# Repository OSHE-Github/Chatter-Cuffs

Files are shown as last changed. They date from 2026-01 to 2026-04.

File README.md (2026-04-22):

# Chatter Cuff
Chatter Cuff is a wrist mounted walkie talkie intended for outdoor sporting enthusiasts.
<br/>

<p align="center">
  oshe logo
<p/>

## Project Details
The Chatter Cuff is a student-led project sponsored by the OSHE enterprise, created to solve the limitations of traditional walkie talkies in cold-weather sports. Designed as a forearm-mounted communication device, it offers glove-friendly usability, weather-resistant electronics, and comfortable wearability. This is made ideal for skiers, snowboarders, and outdoor adventurers who need reliable communication in remote environments. Over the course of two semesters, the team prototyped, refined, and finalized a durable, user-friendly product that reimagines how slope-side communication can be both practical and intuitive. By prioritizing comfort, durability, and ease of use, the Chatter Cuff represents a meaningful leap in wearable technology for outdoor recreation.

Beyond its immediate benefits to adventurers, the project provided students with a hands-on opportunity to integrate electronics, CAD design, and user-centered engineering into a real-world product. For the broader industry, it introduces a new user experience that could influence future designs in sports technology, emergency response gear, and wearable electronics. As for the OSHE enterprise, the Chatter Cuff offers visibility and recognition as the device is seen in action on the slopes. In combining technical innovation with practical usability, this project not only enhances safety and connectivity in extreme environments but also positions itself as a showcase of student ingenuity and enterprise impact.

The Chatter Cuff project provides a mostly unique take on the walkie talkie format, providing users with a glove enclosure to slip under jackets and gloves for ease of use and comfort. Using an ESP32-C3-WROOM and 
the ESP-NOW wireless communication protocol, 2 Chatter Cuffs can communicate back and forth with ease.

<p align="center">
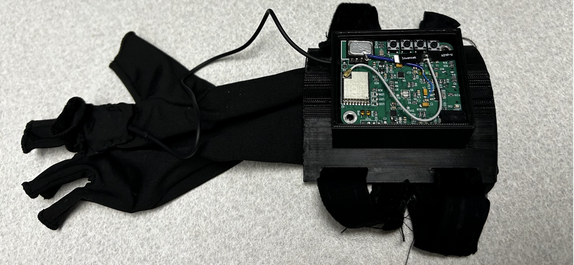
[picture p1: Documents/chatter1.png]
An open chatter cuff
  
<p/>

<p align="center">
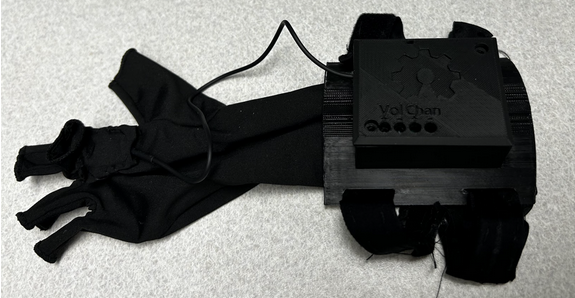
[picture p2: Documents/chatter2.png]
A closed chatter cuff
  
<p/>

## Repository Structure
Here is what's in each folder:
1. [Documents](https://github.com/OSHE-Github/Chatter-Cuffs/tree/main/Documents)
    - Documentation about the project including testing results
    - Media files for readmes
2. [Hardware](https://github.com/OSHE-Github/Chatter-Cuffs/tree/main/Hardware)
    - Gerber files and other resources for making your own Chatter Cuff
3. [walkie-talkie](https://github.com/OSHE-Github/Chatter-Cuffs/tree/main/walkie-talkie)
    - Project code and libraries

## Tools Used
| Tool/Programs | Description |
| --- | --- |
| Heat Gun (or reflow oven if available) | To solder the small SMT components |
| Solder Paste | Used in tandem with Heat Gun |
| Soldering Iron | Creating electrical connections between the wires |
| Screwdriver | Screwed the enclosure together |
| Tweesers | Component Placement |
| Flux | Tinning wires |
| Wire Strippers/Cutters | Stripping Wires for transmit button |
| Needle with Thread | Seating the button on the compression glove for the device. |
| Hobby Knife | To spread solder paste on circuit board |
| 3D Printer (Used an X1 Carbon but could be any 3D printer) | Printed the enclosure for all the components |
| OnShape | Program used to model the enclosure to then export, slice, and print |
| Bambu Studio | Slicer used to print the enclosure |
| Platform IO in VS code | For creating the program and programming the ESP-32 |
| KiCAD | Designing the condensed PCB |

### Features
- Long-range ESP-32 based transmission and receiving
- Battery power for extended outdoor use
- Tough external shell designed to be impact resistant
- Easily accessible transmit button and volume/channel switching buttons

### Bill of Materials
| Part Number | Description | Designator | Cost | Quantity | Total Cost |
| --- | --- | --- | --- | --- | --- |
| SM02B-SRSS-TB | Battery Connector | Batt | $0.38  | 1 | $0.38 |
| GMT21X7R105K25NT3  | 1uF Cap (Ceramic) | C1, C11, C13 | $0.20  | 3 | $0.60 |
| C0805C104K5RAC7210 | 0.1uF Cap (Ceramic) | C2, C4, C7, C8, C14 | $0.13  | 5 | $0.65 |
| T491A475K025AT | 4.7uF Cap (Tantalum) | C3 | $0.46  | 1 | $0.46 |
| C0805C104K5RAC7210 | 0.1uF Cap (Tantalum) | C5, C9, C17 | $0.13  | 3 | $0.39 |
| T491A106M010AT | 10uF Cap (Tantalum) | C6, C10, C16 | $0.13  | 3 | $0.39 |
| C0805C106K8PACTU | 10 uF Cap  (Ceramic) | C12 | $0.39  | 1 | $0.39 |
| CHV0805N250221FCT  | 220pF Cap  (Ceramic) | C15, C18 | $0.42  | 2 | $0.84 |
| 1825910-6 | TH Push Buttons | Ch+, Ch-, Vol+, Vol- | $0.13  | 4 | $0.52 |
| LTST-C170KRKT | Red SMT LEDs | CH, Vol, L1, L2, L3, L4, RX, LED3, PWR | $0.15  | 9 | $1.35 |
| 0ZCH0110AF2E | Fuse (1.1A, 16V, 1210) | F1 | $0.31  | 1 | $0.31 |
| MI1206L501R-10 | Ferrite Beads | FB1, FB2 | $0.23  | 2 | $0.46 |
| MAX98357AETE+T | Amplifier IC | U9 | $3.73  | 1 | $3.73 |
| 1003-030-01210-TR  | USB-C | J1 | $0.98  | 1 | $0.98 |
| STX-3000 | Audio Jack | Jack | $0.65  | 1 | $0.65 |
| LTST-C170TBKT | Blue SMT LED | LED1 | $0.23  | 1 | $0.23 |
| LTST-C170GK | Green SMT LED | LED2, TX | $0.10  | 2 | $0.20 |
| MMICT5837-00-012 | New SMT Microphone | MIC | $2.40  | 1 | $2.40 |
| JS102011SAQN | SMT Switch | On/Off, SW | $0.78  | 2 | $1.56 |
| BCW66HTA | Transistors | Q1, Q2 | $0.39  | 2 | $0.78 |
| RC0805FR-1022K1L | 22.1k Resistor | R1 | $0.10  | 1 | $0.10 |
| RC0805FR-0747K5L | 47.5k Resistor | R2 | $0.10  | 1 | $0.10 |
| RC0805JR-075K1L | 5.1k Resistor | R3, R11 | $0.10  | 2 | $0.20 |
| RC0805JR-131KL | 1k Resistor | R4 | $0.10  | 1 | $0.10 |
| RC0805JR-070RL | 0-Ohm Resistor | R5, R6 | $0.10  | 2 | $0.20 |
| RC0805FR-07470RL | 470 Ohm Resistor | R7, R9, R10, R12, R13, R14, R15, R16, R17, R18, R19, R20, R21, R22, R23, R24, R26 | $0.10  | 17 | $1.70 |
| ESP32-C3-WROOM-02U | ESP-32 | U3 | $3.50  | 1 | $3.50 |
| RC0805FR-0747KL | 4.7k Resistor | R8 | $0.10  | 1 | $0.10 |
| RC0805FR-07100KL | 100k Resistor | R25 | $0.10  | 1 | $0.10 |
| RC0805JR-071ML | 1M Resistor | R27 | $0.10  | 1 | $0.10 |
| RC0805FR-0710KL | 10k Resistor | R28, R29, R30, R31, R32 | $0.10  | 5 | $0.50 |
| RC0805FR-102KL | 2k Resistor | R33 | $0.10  | 1 | $0.10 |
| RC0805FR-0720KL | 20k Resistor | R34 | $0.10  | 1 | $0.10 |
| USLPT2819DT2TR | SMT Buttons (boot/reset) | Boot, Reset | $0.81  | 2 | $1.62 |
| CMS-151125-078L100 | Speaker (8 ohm) | Speaker | $2.96  | 1 | $2.96 |
| CP2102N-A02-GQFN20 | USB Bridge, USB to UART | U2 | $4.48  | 1 | $4.48 |
| USBLC6-2SC6 | TVS Diode | U1 | $0.36  | 1 | $0.36 |
| LM1117MPX-3.3/NOPB | Linear Regulator | VR1 | 1.07 | 1 | $1.07 |
| MCP73871T-1AAI/ML  | Battery Management IC | U5 | $2.41  | 1 | $2.41 |
| ASR00008 | 3.7V, 11mah Lith/ION Battery | N/A | $9.95  | 1 | $9.95 |
| N/A | Compression Glove | N/A | $15.99 | 1 | 15.99 |
| N/A | ⅛ inch plastic elastic cord | N/A | $1.49  | 1 | 1.49 |
| N/A | External Push Button | TXC | $1.30  | 1 | $1.30 |
| N/A | Bare PCBs (JLCPCB, 5 boards at about $60) | N/A | $12 | 1 | $12 |
| N/A | PCB Stencil | N/A | $5 | 1 | $5 |
| N/A | Needle and thread | N/A | $3 | 1 | $3 |

## Assembly Instructions
Start by printing the provided files. PETG is recommended for the main enclosure, as its rigidity is preferred for ruggedness. PLA is recommended for the top to allow buttons to work. If applicable, TPU must be used for the optional gaskets. 

For the main circuit board, utilizing solder paste and a reflow oven is recommended, but not required. It is recommended to purchase solder paste and a stencil for the small surface mount components such as the QFN-20 and to use a heat gun to adhere those components to the PCB. Begin by aligning the stencil to the pads on the PCB. Dispense room temperature solder paste along the openings on the stencil then use a razor blade to evenly spread the paste along the stencil. It is recommended that you only place solder paste on the super small pads at this time as you will be using a heat gun to cure the paste which could in turn also turn other areas of paste to solder if you are not careful. Make sure to firmly hold the stencil in place during this process. Quickly and evenly remove the stencil, taking care not to mess up the solder paste that was just placed on the board. Be sure to prioritize the small ICs before moving onto the resistors and larger components.

Either dispense solder paste onto the larger pads or use a soldering iron to connect the remaining surface mount components (it is easier to solder all the components to the front side of the PCB before placing components on the back side). You can now solder any through hole components to the PCB then any components to the back side of the PCB such as the switches and battery connector. Note that it is easiest to use solder paste on the battery connector then to touch the solder paste with the tip of a hot soldering iron in order to connect the small terminals. Do not solder the transmission button at this time but every other electronic component should now be attached to the PCB.
Cut down the compression glove to the desired length, the glove must be able to reach the back of the enclosure, leaving around a half inch of material to sew the elastic cord around it. Set aside extra material to use for sewing. Mark the desired location of the transmission button, and sew it into place using the extra material. Cut enough elastic cord so that the diameter is slightly less than the glove, with some extra to tie a knot. Tie a knot and sew it into the end of the glove. 

The compression glove is now complete, and ready to be adhered to the enclosure. Gently guide the end of the glove into the notch at the back of the enclosure so the cord sits into the groove. Gluing is not required, but may be helpful to keep the glove in the notch of the enclosure. You may now feed the transmission button wire through the hole at the front of the enclosure and solder the wires onto the board. Attach the antenna to the terminal jack on the ESP-32 and position the antenna within the enclosure.

The hook and loop straps can be made by using no sew tape or sew on hook and loop strips. Use the leftover compression glove material or any scrap fabric you have to make the straps any desired length. The strips should be mostly loop material with the end being the hook material all facing the same direction. Sew one end of the strips onto itself or use more hook and loop material to make the end thick so it won't go through the loops on the enclosure. Feed the finished straps through the backside of the enclosure, or the side facing away from you when wearing it, and feed it over the compression glove, and into the second loop on the enclosure, you can now feed it the other way to secure the device to your arm. You may now screw on the top of the enclosure.  

## Spring 2026 Report
The 2026 Report can be found [here](<Documents/Chatter Cuff Report.pdf>) in Documents

## Acknowledgements
[Atomic14's ESP-32 Walkie-Talkie](https://github.com/atomic14/esp32-walkie-talkie)

## References
[GitHub Doc](https://docs.github.com/en/get-started/writing-on-github/getting-started-with-writing-and-formatting-on-github/basic-writing-and-formatting-syntax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)<br/>
[Open Source Modular Controller README](https://github.com/OSHE-Github/Open-Source-Modular-Controller/blob/main/README.md)

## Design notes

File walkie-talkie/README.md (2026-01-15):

# Overview

We've made a Walkie-Talkie using the ESP32.

[Explanatory video](https://www.youtube.com/watch?v=d_h38X4_eQQ)

Demo Video (https://www.youtube.com/watch?v=d_h38X4_eQQ)

Audio data is transmitted over either UDP broadcast or ESP-NOW. So the Walkie-Talkie will even work without a WiFi network!

I'm using my own microphone board (available on Tindie: https://www.tindie.com/products/21519/) but the code will work equally well with any I2S microphone (e.g. the INMP441) and you can easily modify it to use the built-in ADC for analogue microphones.

For output, I'm using an I2S amplifier breakout board which I'm using the drive a 4ohm speaker. Once again, you can modify the code to use the built-in DAC for output which will let you use headphones or an analogue amplifier board.

I've got a great series of videos on ESP32 Audio which are a great resource for anyone who wants to learn more about audio on the ESP32 which you can find here: https://www.youtube.com/playlist?list=PL5vDt5AALlRfGVUv2x7riDMIOX34udtKD

For this project I've 3D printed a case - you can access the Fusion 360 project here: https://a360.co/2PXgAUS

I've also created a custom PCB - you can access the schematic here: https://easyeda.com/chris_9044/esp32-walkie-talkie

The boards were manufactured by PCBWay and as always they've done a really great job. You can order the boards directly from PCBWay here: https://www.pcbway.com/project/shareproject/ESP32_Audio_Board_For_Walkie_Talkie.html

And you can help support the channel by using my referral link: https://www.pcbway.com/setinvite.aspx?inviteid=403566 for other PCBs.

However, you can also easily wire this up on breadboard - that's how I prototyped it. Everything is I2S based so it's just straightforward jumper wires.

# Setup

Everything is configured from the `src/config.h` file. To use UDP Broadcast comment out the line:

```
#define USE_ESP_NOW
```

Make sure you update the WiFi SSID and Password:

```
// WiFi credentials
#define WIFI_SSID << YOUR_SSID >>
#define WIFI_PSWD << YOUR_PASSWORD >>
```

The pins for the microphone and the amplifier board are all setup in the same `config.h` file.

# Building and Running

I'm using PlatformIO for this project so you will need to have that installed. Open up the project and connect your ESP32. You should be able to just hit build and run.

Obviously, you'll need two ESP32 boards and components to do anything :)

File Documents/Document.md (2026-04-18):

## Distortion Data
The measured total harmonic distortion on the receiving end of a Chatter Cuff to Chatter Cuff test is 6.85% or -23.29dB. This test was performed by transmitting a known signal (1kHz tone) from one Chatter Cuff to the other in direct line of sight. The following screenshots are the oscilloscope measurements during testing.

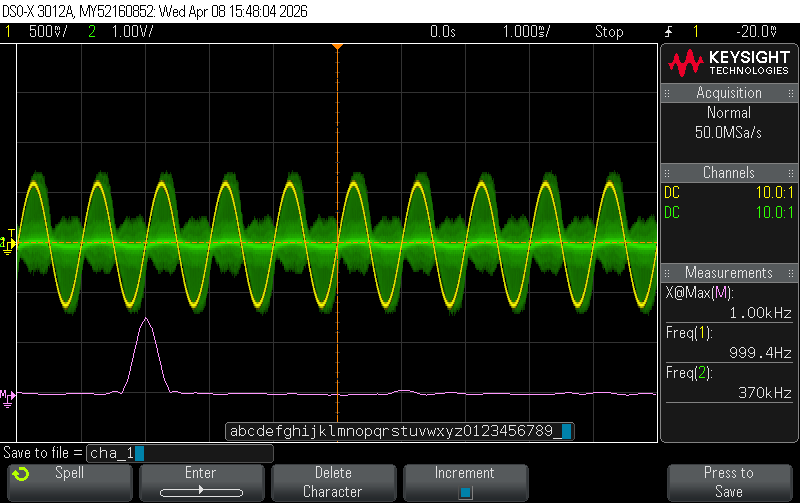
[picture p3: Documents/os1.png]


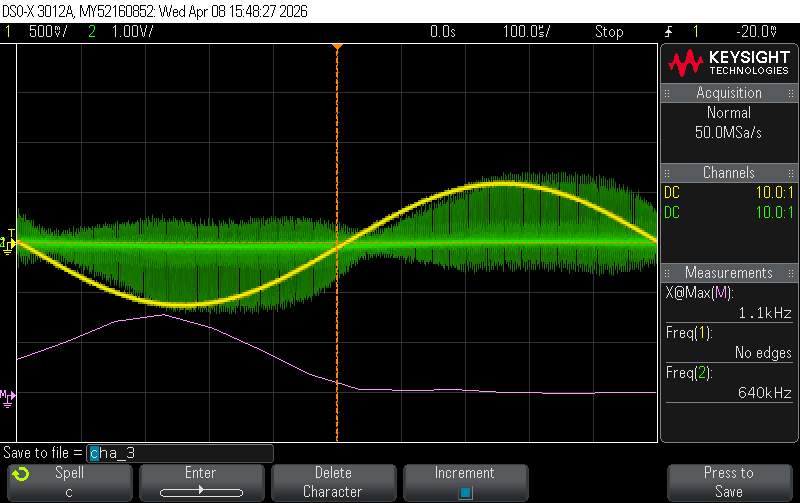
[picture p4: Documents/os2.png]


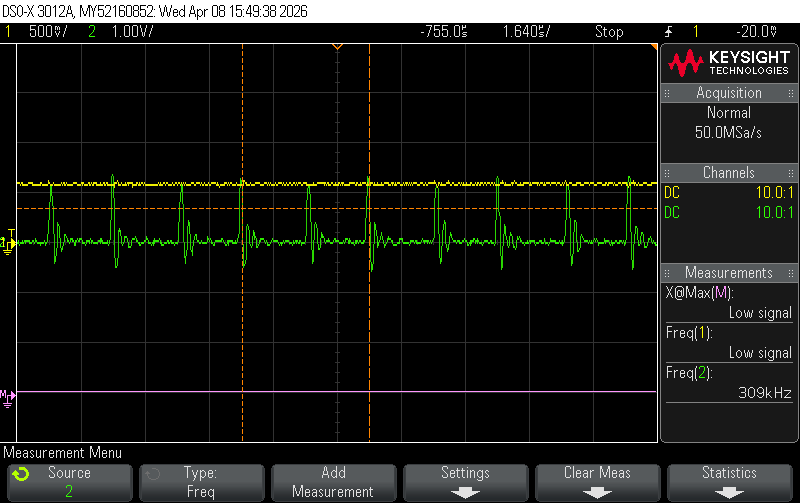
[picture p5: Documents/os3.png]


Additionally, the perceived distortion/signal integrity (to the human ear, tested by the Chatter Cuff team) given different testing conditions is as follows.

| Range | Out of sight | Line of sight |
| ----- | --- | --- |
| 25m | Good Quality | Good Quality  |
| 50m | Poor Quality | Good Quality  |
| 100m  | Zero Quality | Good Quality  |
| 150m  | Zero Quality | Good Quality  |
| 200m  | Zero Quality | Okay Quality  |
| 250m  | Zero Quality | Poor Quality  |

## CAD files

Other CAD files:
Hardware/CAD/Chatter Cuff Assembly.x_t
Hardware/CAD/gasket stencils.x_t
Hardware/CAD/top cad.x_t
Hardware/CAD/wrist mount cad.x_t

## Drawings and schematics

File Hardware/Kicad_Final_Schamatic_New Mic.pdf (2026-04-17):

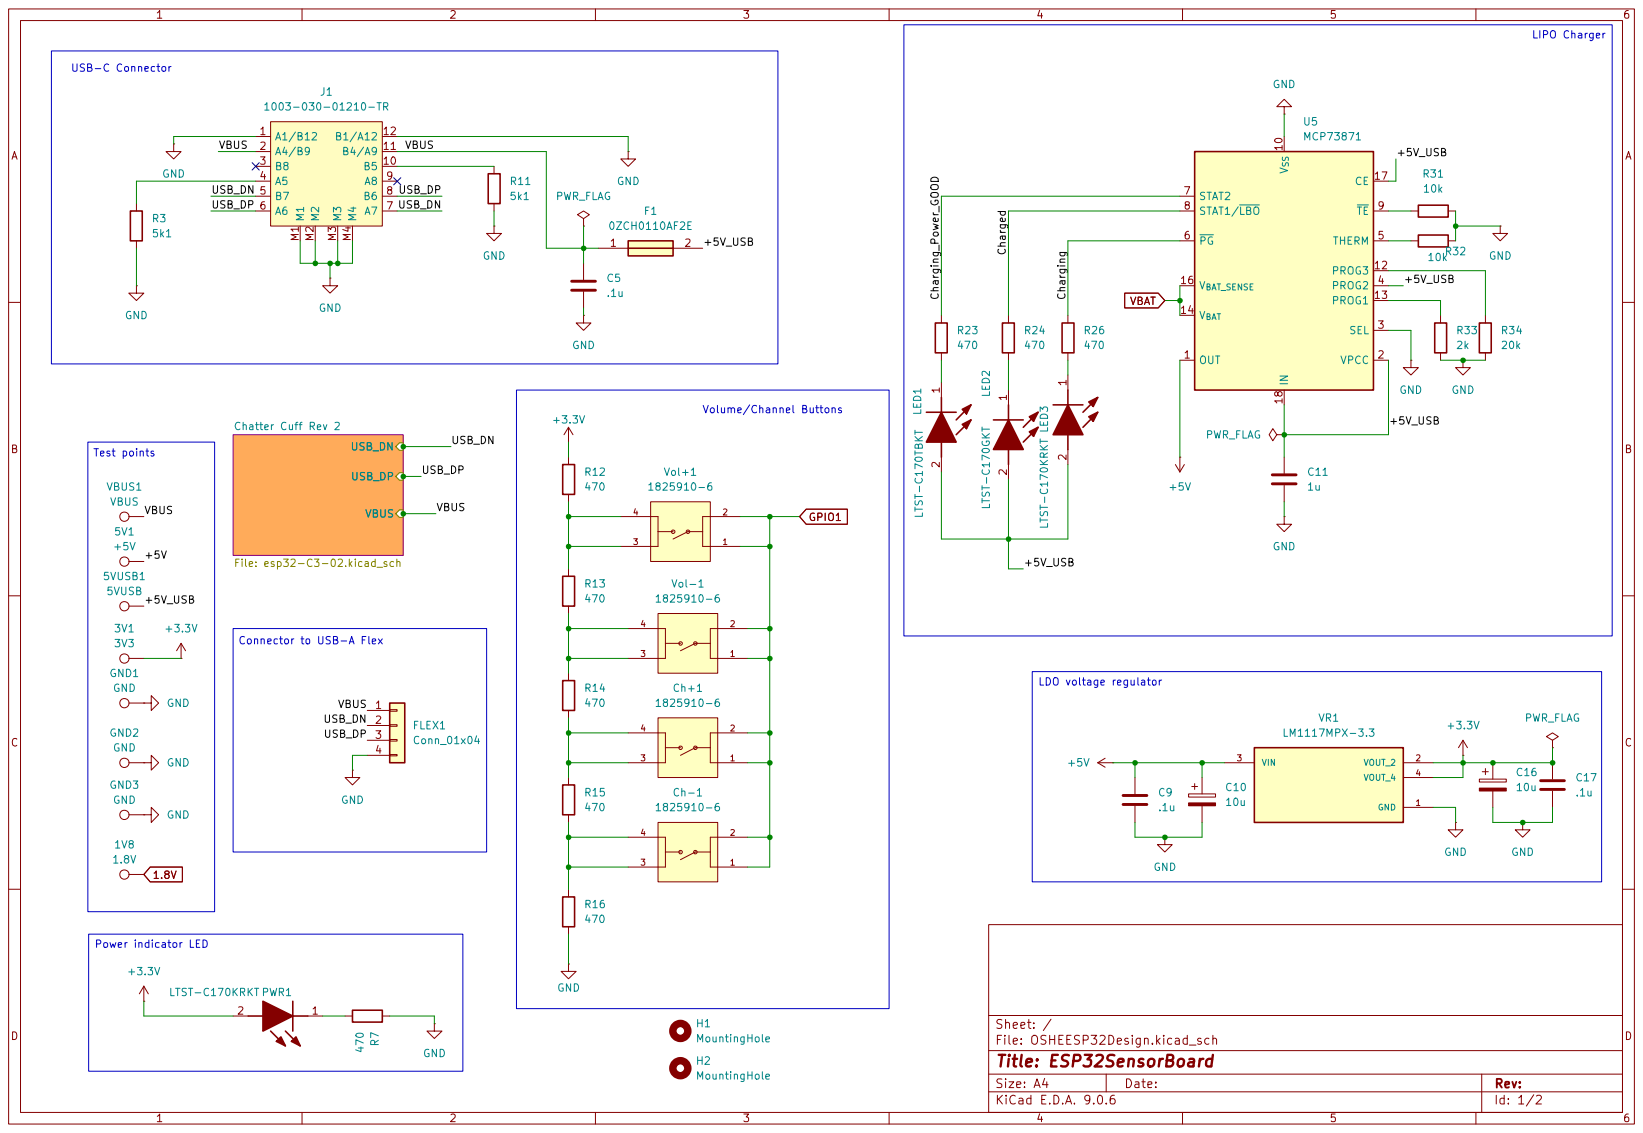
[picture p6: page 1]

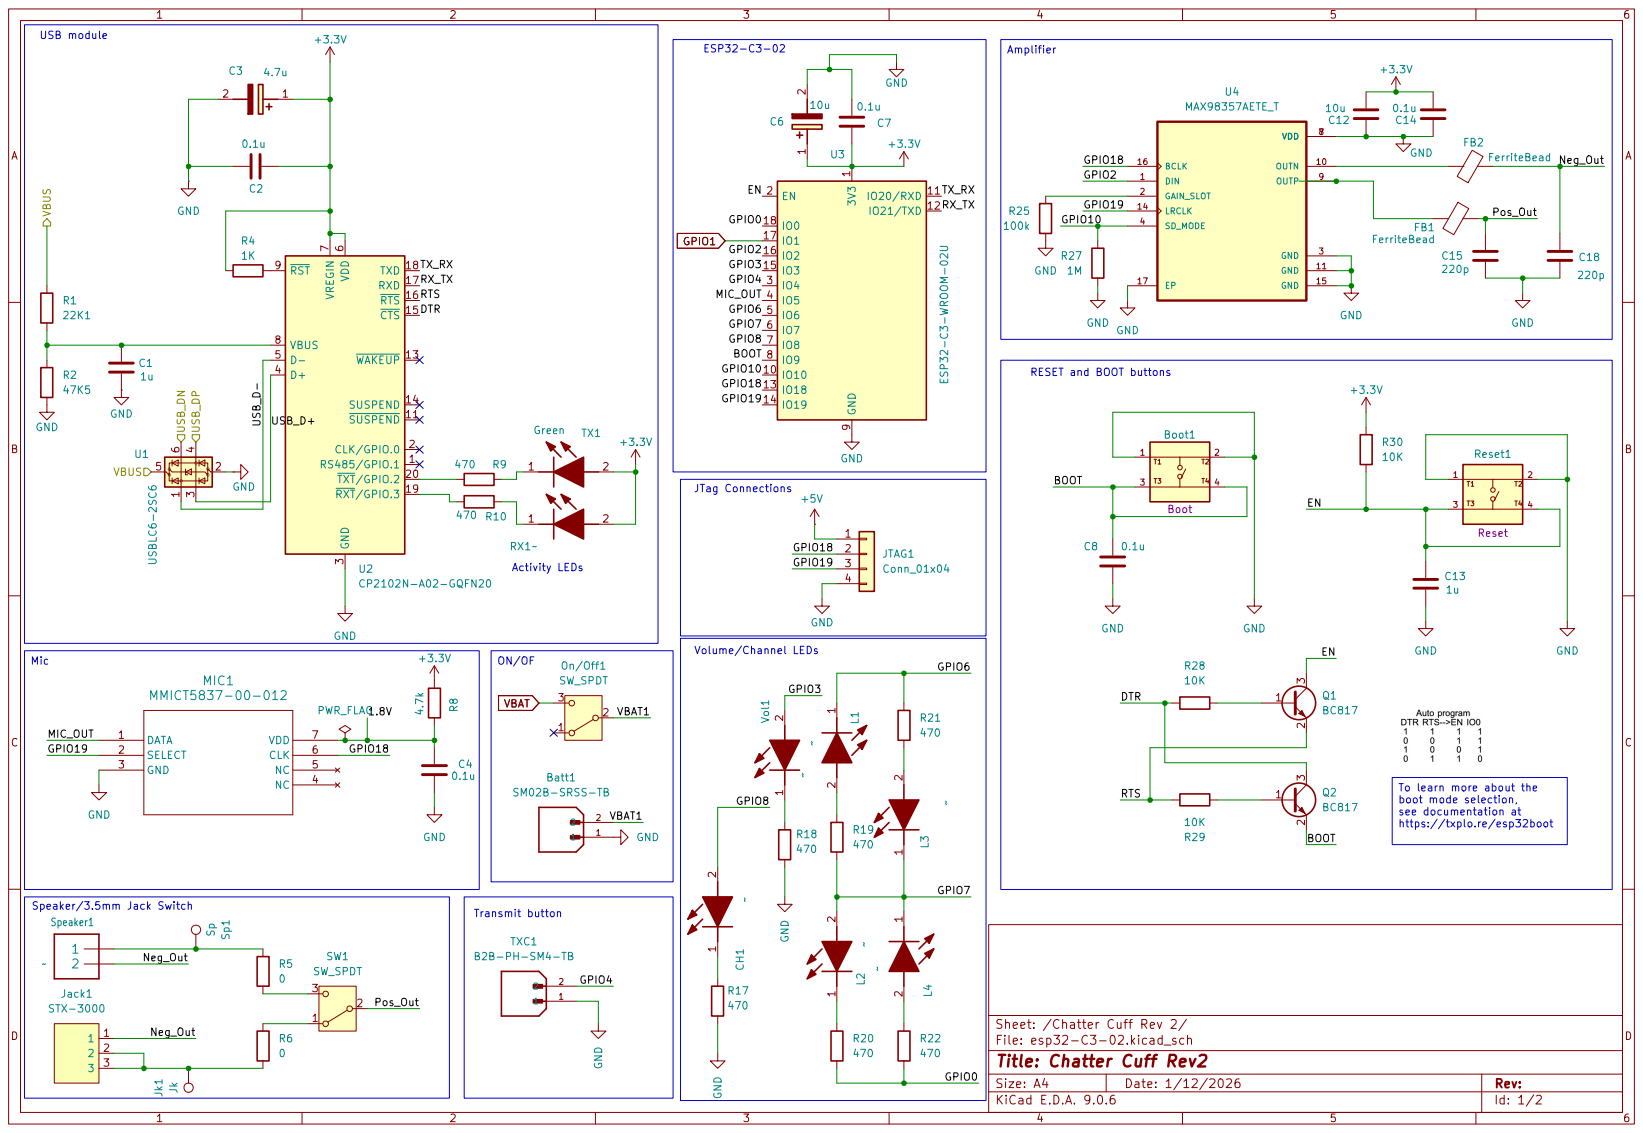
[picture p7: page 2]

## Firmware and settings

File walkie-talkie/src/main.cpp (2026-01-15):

#include <Arduino.h>
#include "Application.h"

// our application
Application *application;

void setup()
{
  Serial.begin(115200);
  // start up the application
  application = new Application();
  application->begin();
  Serial.println("Application started");
}

void loop()
{
  // nothing to do - the application is doing all the work
  vTaskDelay(pdMS_TO_TICKS(1000));
}

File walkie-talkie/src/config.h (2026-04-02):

#include <freertos/FreeRTOS.h>
#include <driver/i2s.h>
#include <driver/gpio.h>

// WiFi credentials
#define WIFI_SSID <<SSID>>
#define WIFI_PSWD <<PSWD>>

// sample rate for the system
#define SAMPLE_RATE 16000

// are you using an I2S microphone - comment this if you want to use an analog mic and ADC input
//#define USE_I2S_MIC_INPUT

// I2S Microphone Settings

// Which channel is the I2S microphone on? I2S_CHANNEL_FMT_ONLY_LEFT or I2S_CHANNEL_FMT_ONLY_RIGHT
// Generally they will default to LEFT - but you may need to attach the L/R pin to GND
#define I2S_MIC_CHANNEL I2S_CHANNEL_FMT_ONLY_LEFT
// #define I2S_MIC_CHANNEL I2S_CHANNEL_FMT_ONLY_RIGHT
#define I2S_MIC_SERIAL_CLOCK GPIO_NUM_18
#define I2S_MIC_LEFT_RIGHT_CLOCK GPIO_NUM_19
#define I2S_MIC_SERIAL_DATA GPIO_NUM_5

// Analog Microphone Settings - ADC1_CHANNEL_7 is GPIO35
#define ADC_MIC_CHANNEL GPIO_5

// speaker settings
#define USE_I2S_SPEAKER_OUTPUT
#define I2S_SPEAKER_SERIAL_CLOCK GPIO_NUM_18
#define I2S_SPEAKER_LEFT_RIGHT_CLOCK GPIO_NUM_19
#define I2S_SPEAKER_SERIAL_DATA GPIO_NUM_2
// Shutdown line if you have this wired up or -1 if you don't
#define I2S_SPEAKER_SD_PIN GPIO_NUM_10

// transmit button
#define GPIO_TRANSMIT_BUTTON GPIO_NUM_4

#define ADC_INPUT_CONTROL_PIN GPIO_NUM_1
#define INPUT_4TH_BOUND 3400
#define INPUT_3RD_BOUND 2500
#define INPUT_2ND_BOUND 1500
#define INPUT_1ST_BOUND 1000
#define INPUT_LOWER_BOUND 900

#define GPIO_LED_LEFT GPIO_NUM_0
#define GPIO_LED_MIDDLE GPIO_NUM_7
#define GPIO_LED_RIGHT GPIO_NUM_6

#define GPIO_VOLUME_INDICATOR_LED GPIO_NUM_3
#define GPIO_CHANNEL_INDICATOR_LED GPIO_NUM_8

// Which LED pin do you want to use? TinyPico LED or the builtin LED of a generic ESP32 board?
// Comment out this line to use the builtin LED of a generic ESP32 board
// #define USE_LED_GENERIC

// Which transport do you want to use? ESP_NOW or UDP?
// comment out this line to use UDP
#define USE_ESP_NOW

// On which wifi channel (1-4) should ESP-Now transmit? The default ESP-Now channel on ESP32 is channel 1
#define ESP_NOW_WIFI_CHANNEL 1
// Channel range for ESP-NOW (1-4 for 2.4GHz WiFi channels)
#define ESP_NOW_CHANNEL_MIN 1
#define ESP_NOW_CHANNEL_MAX 4

// In case all transport packets need a header (to avoid interference with other applications or walkie talkie sets), 
// specify TRANSPORT_HEADER_SIZE (the length in bytes of the header) in the next line, and define the transport header in config.cpp
#define TRANSPORT_HEADER_SIZE 0
extern uint8_t transport_header[TRANSPORT_HEADER_SIZE];


// i2s config for using the internal ADC
extern i2s_config_t i2s_adc_config;
// i2s config for reading from of I2S
extern i2s_config_t i2s_mic_Config;
// i2s microphone pins
extern i2s_pin_config_t i2s_mic_pins;
// i2s speaker pins
extern i2s_pin_config_t i2s_speaker_pins;

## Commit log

2026-01-15 Basic README
    just to have a file in the repo. (I barely know how to use github i'm learning 😭)
2026-01-15 Added Last Semester's Code
    Good starting point, have a local copy on my laptop in case the old repo explodes or something.
2026-03-25 Update Application.cpp to match new control logic
    Added several functions to Application.cpp to handle our new I/O scheme. More specifically, this handles the input buttons on one ADC channel (in handle_inputs()) and outputs to LEDs via the new cont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
2026-03-25 Update config.h to include new control logic/schematic
    As the schematic changed, pins were moved around. This matches the new schematic and also includes the ability to change the thresholds for the ADC input buttons.
2026-04-02 Update Application.cpp to current version
    Updating Application.cpp to the version used in design checkoff. This is the most current version.
2026-04-02 Update config.h to current version
    This includes proper pin assignments and threshold values for the ADC buttons
2026-04-02 Update platformio.ini to current version
    Includes the current uploading method (JTAG, built-in)
2026-04-17 Adding Gerbers
2026-04-17 Adding KiCad Schematic
2026-04-17 Adding CAD File
    [Chatter Cuff Assembly.x_t]
2026-04-17 Rename Chatter Cuff Final Gerbers.zip to Chatter Cuff Gerbers Old Mic.zip
2026-04-17 Add gasket stencil CAD model
    [gasket stencils.x_t]
2026-04-17 Adding separate cad models
    [top cad.x_t, wrist mount cad.x_t]
2026-04-17 Adding New Gerbers
2026-04-17 Rename Chatter Cuff Rev 2 Gerbers New Mic-20260417T194933Z-3-001.zip to Chatter Cuff Gerbers Final.zip
2026-04-17 Adding CAD Folder for models.
    [Chatter Cuff Assembly.x_t]
2026-04-17 Add gasket stencils to CAD Folder
    [gasket stencils.x_t]
2026-04-17 Rename Hardware/top cad.x_t to Hardware/CAD/top cad.x_t
    [top cad.x_t]
2026-04-17 Rename Hardware/wrist mount cad.x_t to Hardware/CAD/wrist mount cad.x_t
    [wrist mount cad.x_t]
